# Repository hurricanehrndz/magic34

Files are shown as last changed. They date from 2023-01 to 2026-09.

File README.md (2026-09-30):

# Magic34

Custom 34 key keyboard that feels like magic!

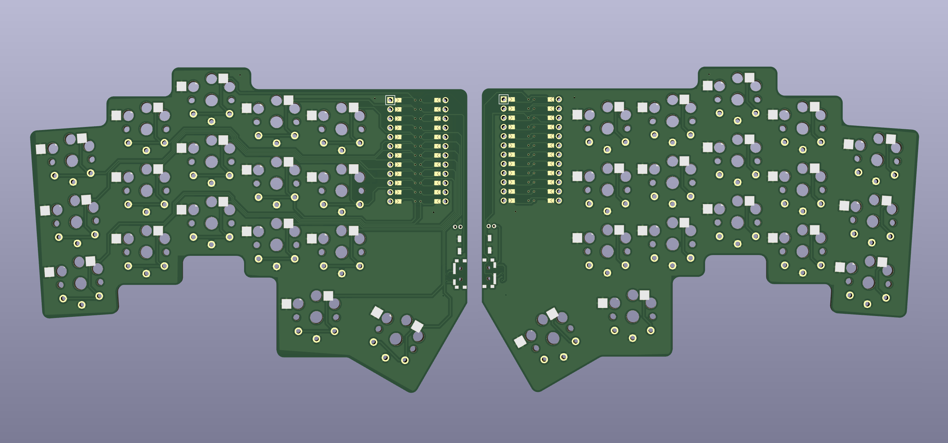
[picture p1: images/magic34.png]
magic34 PCB


## Design

More info coming soon!

## Firmware

CI builds everything in `build.yaml`. Flash `settings_reset` on every board
before switching between these setups:

- Without a dongle: `magic34_left` (central) and `magic34_right`.
- With a USB dongle: `magic34_dongle`, `magic34_left_peripheral`, and
  `magic34_right`. The dongle pairs with both halves on its own and shows up
  on the host as a USB keyboard.

The dongle build also works on cheap nice!nano clones that lack the 32 kHz
crystal and DC/DC inductors. The halves run on battery and need DC/DC, so use
genuine nice!nanos for them.

[magic34pcb]: images/magic34.png

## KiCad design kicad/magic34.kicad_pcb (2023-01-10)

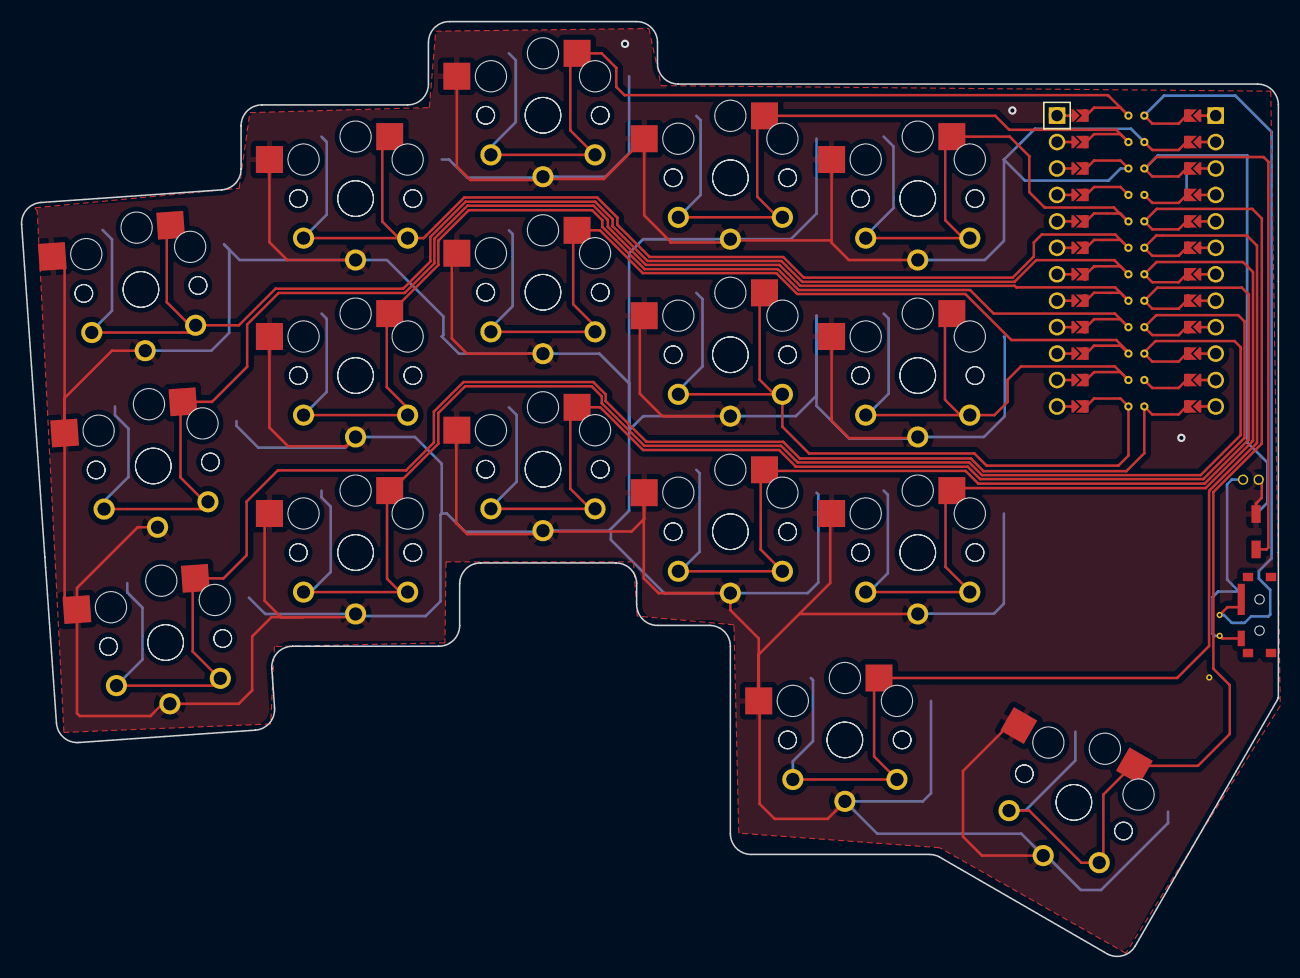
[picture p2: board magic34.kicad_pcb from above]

Board: 2 copper layers, 120.7 x 89.8 mm, 35 parts (0 on the bottom side), 18 nets.

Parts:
MCU1: ProMicro
S1, S2, S3, S4, S5, S6, S7, S8, S9, S10, S11, S12, S13, S14, S15, S16, S17, S18, S19, S20, S21, S22, S23, S24, S25, S26, S27, S28, S29, S30, S31, S32, S33, S34: PG1350

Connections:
GND: MCU1.2, MCU1.21, MCU1.22, S1.2, S2.2, S3.2, S4.2, S5.2, S6.2, S7.2, S8.2, S9.2, S10.2, S11.2, S12.2, S13.2, S14.2, S15.2, S16.2, S17.2, S18.2, S19.2, S20.2, S21.2, S22.2, S23.2, S24.2, S25.2, S26.2, S27.2, S28.2, S29.2, S30.2, S31.2, S32.2, S33.2, S34.2
P0: MCU1.23, S23.1, S24.1
P1: MCU1.24, S17.1, S18.1
P2: MCU1.20, S29.1, S30.1
P3: MCU1.19, S11.1, S12.1
P4: MCU1.18, S5.1, S6.1
P5: MCU1.17, S3.1, S4.1
P6: MCU1.16, S9.1, S10.1
P7: MCU1.15, S15.1, S16.1
P8: MCU1.14, S27.1, S28.1
P9: MCU1.13, S21.1, S22.1
P10: MCU1.12, S1.1, S2.1
P14: MCU1.10, S7.1, S8.1
P15: MCU1.9, S13.1, S14.1
P18: MCU1.8, S19.1, S20.1
P19: MCU1.7, S25.1, S26.1
P20: MCU1.6, S31.1, S32.1
P21: MCU1.5, S33.1, S34.1

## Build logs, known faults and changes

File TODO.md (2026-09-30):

# TODO

## Fit the layout to my hands

Tune `ergogen/magic34.yaml` (column stagger, splay, thumb cluster) from real
hand measurements instead of the current defaults (8 mm stagger, ±4° splay).

1. Measure hands, trying these in order:
   - Ergopad (`pashutk.com/ergopad`) on the iPad: tap each finger through
     the three rows. It's unfinished and has no export, so give it five
     minutes and move on if it can't give stagger and splay in mm.
   - Cosmos hand scan (`ryanis.cool/cosmos`) on the iPad camera, scanned a
     few times to check consistency.
   - Last resort: build a single-page iPad touch tool that records
     fingertip positions in mm.
2. Update stagger and splay only, regenerate, print the outline 1:1 with
   keycaps drawn, and test by typing on paper.
3. Then adjust the thumb cluster and MCU/battery placement.
4. Re-route the PCB in KiCad before ordering.

## Go to 36 keys

Each half direct-wires 17 of the 18 Pro Micro pins, so a third thumb key fits
on the free pin `P16` (confirm it on the nice!nano pinout first). Add a column
to the `thumbfan` zone, add one thumb binding per side in the keymap, and
consider giving Shift its own thumb key. Do this in the same PCB revision as
the hand-fit changes, and add mounting holes to that revision.

## 3D-printed case

Do this last: the hand-fit and 36-key changes both move the outline. Add a
`cases:` section to the ergogen file that extrudes `cutout` into a tray with a
2-3 mm wall, then export JSCAD and convert it to STL. Plan on 1-3 test prints
for the MCU, battery, and USB clearance. For printing, look for a used printer
on Marketplace.

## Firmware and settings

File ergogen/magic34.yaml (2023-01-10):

units:
  mcu_width: 33
  mcu_height: 18
  batt_width: 11.5
  batt_length: 31.8
  batt_padding: 1.5

points:
  key:
    padding: cy
    footprints:
      choc_hotswap:
        type: choc
        nets:
          from: =column_net
          to: GND
        params:
            keycaps: true
            reverse: true
            hotswap: true
      choc:
        type: choc
        anchor:
          rotate: 180
        nets:
          from: =column_net
          to: GND
        params:
            keycaps: true
            reverse: true

  zones:
    matrix:
      rows:
        bottom:
        home:
        top:
      columns:
          pinkie:
            rotate: 4
            spread: cx
            row_overrides:
              bottom:
                bind: [0,1,0,2]
                column_net: P10
              home:
                column_net: P5
                bind: [0,3,0,2]
              top:
                column_net: P4
                bind: [0,6,0,2]
          ring:
            rotate: -4
            origin: [-9, -9]
            stagger: 8
            spread: cx+0.2
            rows:
              bottom:
                bind: [0,1,0,0]
                column_net: P14
              home:
                bind: [0,1,0,0]
                column_net: P6
              top:
                column_net: P3
                bind: [0,0,0,2]
          middle:
            stagger: 8
            spread: cx
            rows:
              bottom:
                bind: [0,1,0,0]
                column_net: P15
              home:
                bind: [0,1,0,0]
                column_net: P7
              top:
                column_net: P1
                bind: [0,2,0,2]
          index:
            stagger: -6
            spread: cx
            rows:
              bottom:
                bind: [0,1,0,0]
                column_net: P18
              home:
                bind: [0,1,0,0]
                column_net: P9
              top:
                bind: [0,1,0,0]
                column_net: P0
          far:
            stagger: -2
            spread: cx
            rows:
              bottom:
                column_net: P19
                bind: [0,25.64,5,0]
              home:
                column_net: P8
                bind: [0,25.64,0,0]
              top:
                column_net: P2
                bind: [2,25.64,0,0]
    thumbfan:
      anchor:
        ref: matrix_far_bottom
        shift: [-7, -18]
      columns:
        near:
          rows:
            thumb:
              bind: [2,8,2,2]
              column_net: P20
        home:
          spread: cx+4
          rotate: -30
          stagger: -6
          rows:
            thumb:
              bind: [9.5,3,2,1]
              column_net: P21
      rows:
        thumb:

outlines:
  exports:
    _mcu:
      - type: rectangle
        size: [mcu_width, mcu_height]
        anchor:
          rotate: 270
          ref: matrix_far_top
          shift: [10, 10]
    raw:
      - type: keys
        side: left
        size: [1cx , 1cx]
    cutout:
      - type: outline
        name: raw
        fillet: 2
    keycap_outlines:
      - type: keys
        side: both
        size: [1cx - 0.5, 1cy - 0.5] # Choc keycaps are 17.5 x 16.5
        bound: false
    final:
      - cutout
      - type: outline
        name: keycap_outlines
        operation: subtract
      - type: outline
        name: _mcu
        operation: stack


pcbs:
  magic34:
    outlines:
      main:
        outline: cutout
    footprints:
      pcm12:
        type: pcm12
        anchor:
          ref: matrix_far_bottom
          shift: [+32.5, -6]
          rotate: 90
        nets:
          from: pos
          to: RAW
        params:
          reverse: true
      b3u1000p:
        type: b3u1000p
        nets:
          r1: RST
          r2: GND
        anchor:
          ref: matrix_far_bottom
          shift: [+32.5, +2]
          rotate: 270
        params:
          reverse: true
      bat:
        type: bat
        nets:
          neg: GND
          pos: pos
        anchor:
          ref: matrix_far_home
          shift: [32, -10]
          rotate: 90
      via4:
        type: via
        anchor:
          ref: matrix_far_bottom
          shift: [29,-8]
        nets:
          net: pos
      via6:
        type: via
        anchor:
          ref: matrix_far_bottom
          shift: [29,-6]
        nets:
          net: RAW
      via5:
        type: via
        anchor:
          ref: matrix_far_bottom
          shift: [28,-12]
        nets:
          net: GND
      promicro:
        type: promicro_pretty
        anchor:
          ref: matrix_far_top
          shift: [cx+3, -6]
          rotate: 270

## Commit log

2023-01-10 Initial commit
    This commit includes ergogen v3 input and kicad files.
    [magic34.kicad_pcb]
2023-01-11 Fix typo in devicetree file
2023-01-12 Add PCB image of magic34
2026-01-05 Update board name
2026-09-30 feat(keymap): add thumb tap keys, BT profile select, and flow tap
    Tap NUM/SYM thumbs for Enter/Backspace, fix misspelled quick-tap-ms and
    replace global-quick-tap with require-prior-idle-ms, add pipe and Insert,
    add BT_SEL 0-2 on FUN, and enable experimental BLE connection settings.
2026-09-30 fix(build): use nice_nano//zmk board variant for Zephyr 4.1
2026-09-30 docs: update TODO for 36 keys, case, dongle status, and Ergopad
2026-09-30 fix(dongle): use internal RC oscillator for clone boards
2026-09-30 fix(dongle): use LDO regulator for clone boards
